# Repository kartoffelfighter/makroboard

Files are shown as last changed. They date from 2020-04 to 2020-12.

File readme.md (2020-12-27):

# Makroboard 

This keyboard has 8 cherry switches and 8 rgb-leds, connected to an ATMEGA32U4 (Arduino Leonardo) to emulate a keyboard.

Its porpuse is to store Makros which are not defined per default on a keyboard

## Keys

Default layout (in firmware folder)

| CTRL + F1  | CTRL + F2 | CTRL + F3  | CTRL + F4  |
| --- | --- | --- | --- |
| Media_PREV | Media_PAUSE | Media_NEXT | Media_STOP |
| | | | |
## Dependencies

The firmware uses the FastLed and Project-HID Librarys. You can find these on github, but also in the arduino library manager.

[FastLed (FastLED)]: https://github.com/FastLED/FastLED
[Project-HID (NicoHood)]: https://github.com/NicoHood/HID

### Notes

The Source code is not optimized and might hang sometimes. Since i'm using this board at most to control my teamspeak-mute i didn't care to optimize. If you wan't to, feel free.

Software and Hardware come as-is without any warranty.

My board was etched at jlcpcb, parts came from mouser, assembling was done by hand. 

If you're interested in a board feel free to contact me, i do still have some laying here.

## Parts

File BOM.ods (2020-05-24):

 | Artikel | Preis | Stk | Gesamt
 | Leiterplatte | 1,68 € | 1 | 1,68 €
 | Cherry Switch | 0,43 € | 8 | 3,41 €
 | ATMEGA | 3,60 € | 1 | 3,60 €
 | Quarz | 0,36 € | 1 | 0,36 €
 | Type-C Buchse | 1,58 € | 1 | 1,58 €
 | Neopixel LED | 0,10 € | 8 | 0,80 €
 |  |  |  | 11,42 €
PCB
 | 100nF |  | 10
 | 22pF |  | 2
 | 1µF |  | 1
 | WS2812B |  | 8
 | Type-C Buchse |  | 1
 | 10k |  | 9
 | 22R |  | 2
 | 0R0 |  | 1
 | Varistor |  | 2
 | Cherry Switch |  | 8
 | ATMEGA |  | 1
 | 16MHz |  | 1

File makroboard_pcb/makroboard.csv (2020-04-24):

Source: | C:\Users\marc\Google Drive\Projekte\makroboard\makroboard_pcb\makroboard.sch
Date: | 18.04.2020 20:56:32
Tool: | Eeschema (5.1.5)-3
Component Count: | 73
Ref | Value | Footprint | Datasheet | Manufacturer | Vendor
C1 | 100n | Capacitor_SMD:C_0603_1608Metric | ~
C2 | 100n | Capacitor_SMD:C_0603_1608Metric | ~
C3 | 100n | Capacitor_SMD:C_0603_1608Metric | ~
C4 | 100n | Capacitor_SMD:C_0603_1608Metric | ~
C5 | 100n | Capacitor_SMD:C_0603_1608Metric | ~
C6 | 100n | Capacitor_SMD:C_0603_1608Metric | ~
C7 | 100n | Capacitor_SMD:C_0603_1608Metric | ~
C8 | 100n | Capacitor_SMD:C_0603_1608Metric | ~
C9 | 100n | Capacitor_SMD:C_0603_1608Metric | ~
C10 | 100n | Capacitor_SMD:C_0603_1608Metric | ~
C11 | 22pF | Capacitor_SMD:C_0603_1608Metric | ~
C12 | 22pF | Capacitor_SMD:C_0603_1608Metric | ~
C13 | 100n | Capacitor_SMD:C_0603_1608Metric | ~
C14 | 1µ | Capacitor_SMD:C_0603_1608Metric | ~
C15 | C | Capacitor_SMD:C_0603_1608Metric | ~
C16 | C | Capacitor_SMD:C_0603_1608Metric | ~
C17 | CP | Capacitor_SMD:C_1206_3216Metric | ~
D1 | WS2812B | LED_SMD:LED_WS2812B_PLCC4_5.0x5.0mm_P3.2mm | https://cdn-shop.adafruit.com/datasheets/WS2812B.pdf
D2 | WS2812B | LED_SMD:LED_WS2812B_PLCC4_5.0x5.0mm_P3.2mm | https://cdn-shop.adafruit.com/datasheets/WS2812B.pdf
D3 | WS2812B | LED_SMD:LED_WS2812B_PLCC4_5.0x5.0mm_P3.2mm | https://cdn-shop.adafruit.com/datasheets/WS2812B.pdf
D4 | WS2812B | LED_SMD:LED_WS2812B_PLCC4_5.0x5.0mm_P3.2mm | https://cdn-shop.adafruit.com/datasheets/WS2812B.pdf
D5 | WS2812B | LED_SMD:LED_WS2812B_PLCC4_5.0x5.0mm_P3.2mm | https://cdn-shop.adafruit.com/datasheets/WS2812B.pdf
D6 | WS2812B | LED_SMD:LED_WS2812B_PLCC4_5.0x5.0mm_P3.2mm | https://cdn-shop.adafruit.com/datasheets/WS2812B.pdf
D7 | WS2812B | LED_SMD:LED_WS2812B_PLCC4_5.0x5.0mm_P3.2mm | https://cdn-shop.adafruit.com/datasheets/WS2812B.pdf
D8 | WS2812B | LED_SMD:LED_WS2812B_PLCC4_5.0x5.0mm_P3.2mm | https://cdn-shop.adafruit.com/datasheets/WS2812B.pdf
H1 | MountingHole_Pad | MountingHole:MountingHole_3.2mm_M3_Pad | ~
H2 | MountingHole_Pad | MountingHole:MountingHole_3.2mm_M3_Pad | ~
H3 | MountingHole_Pad | MountingHole:MountingHole_3.2mm_M3_Pad | ~
H4 | MountingHole_Pad | MountingHole:MountingHole_3.2mm_M3_Pad | ~
J1 | TX1+ | TestPoint:TestPoint_Pad_D1.0mm | ~
J2 | TX1- | TestPoint:TestPoint_Pad_D1.0mm | ~
J3 | TX2+ | TestPoint:TestPoint_Pad_D1.0mm | ~
J4 | TX2- | TestPoint:TestPoint_Pad_D1.0mm | ~
J5 | SBU1 | TestPoint:TestPoint_Pad_D1.0mm | ~
J6 | SBU2 | TestPoint:TestPoint_Pad_D1.0mm | ~
J7 | RX1+ | TestPoint:TestPoint_Pad_D1.0mm | ~
J8 | RX1- | TestPoint:TestPoint_Pad_D1.0mm | ~
J9 | RX2+ | TestPoint:TestPoint_Pad_D1.0mm | ~
J10 | RX2- | TestPoint:TestPoint_Pad_D1.0mm | ~
J11 | 105450-0101 | type-c:MOLEX_105450-0101 | Molex
J12 | ICSP | Connector_PinHeader_2.54mm:PinHeader_2x03_P2.54mm_Vertical | ~
J13 | +5V | Connector_PinHeader_2.54mm:PinHeader_1x10_P2.54mm_Vertical | ~
J14 | DIG_IO_2 | Connector_PinHeader_2.54mm:PinHeader_1x10_P2.54mm_Vertical | ~
J15 | DIG_IO_1 | Connector_PinHeader_2.54mm:PinHeader_1x10_P2.54mm_Vertical | ~
J16 | GND | Connector_PinHeader_2.54mm:PinHeader_1x10_P2.54mm_Vertical | ~
J17 | ANALOG_IO | Connector_PinHeader_2.54mm:PinHeader_1x06_P2.54mm_Vertical | ~
R1 | 10k | Resistor_SMD:R_0603_1608Metric | ~
R2 | 10k | Resistor_SMD:R_0603_1608Metric | ~
R3 | 10k | Resistor_SMD:R_0603_1608Metric | ~
R4 | 10k | Resistor_SMD:R_0603_1608Metric | ~
R5 | 10k | Resistor_SMD:R_0603_1608Metric | ~
R6 | 10k | Resistor_SMD:R_0603_1608Metric | ~
R7 | 10k | Resistor_SMD:R_0603_1608Metric | ~
R8 | 10k | Resistor_SMD:R_0603_1608Metric | ~
R9 | 10k | Resistor_SMD:R_0603_1608Metric | ~
R10 | 10k | Resistor_SMD:R_0603_1608Metric | ~
R11 | n.b. | Resistor_SMD:R_0603_1608Metric | ~
R12 | 56k | Resistor_SMD:R_0603_1608Metric | ~
R13 | 22R | Resistor_SMD:R_0603_1608Metric | ~
R14 | 22R | Resistor_SMD:R_0603_1608Metric | ~
R15 | 0R0 | Resistor_SMD:R_0603_1608Metric | ~
RV1 | Varistor | Resistor_SMD:R_0603_1608Metric | ~
RV2 | Varistor | Resistor_SMD:R_0603_1608Metric | ~
SW1 | SW_Push | Button_Switch_Keyboard:SW_Cherry_MX_1.50u_PCB | ~
SW2 | SW_Push | Button_Switch_Keyboard:SW_Cherry_MX_1.50u_PCB | ~
SW3 | SW_Push | Button_Switch_Keyboard:SW_Cherry_MX_1.50u_PCB | ~
SW4 | SW_Push | Button_Switch_Keyboard:SW_Cherry_MX_1.50u_PCB | ~
SW5 | SW_Push | Button_Switch_Keyboard:SW_Cherry_MX_1.50u_PCB | ~
SW6 | SW_Push | Button_Switch_Keyboard:SW_Cherry_MX_1.50u_PCB | ~
SW7 | SW_Push | Button_Switch_Keyboard:SW_Cherry_MX_1.50u_PCB | ~
SW8 | SW_Push | Button_Switch_Keyboard:SW_Cherry_MX_1.50u_PCB | ~
U1 | ATmega32U4-AU | Package_QFP:TQFP-44_10x10mm_P0.8mm | http://ww1.microchip.com/downloads/en/DeviceDoc/Atmel-7766-8-bit-AVR-ATmega16U4-32U4_Datasheet.pdf
Y1 | 16MHz | Crystal:Crystal_SMD_SeikoEpson_MA505-2Pin_12.7x5.1mm_HandSoldering | ~

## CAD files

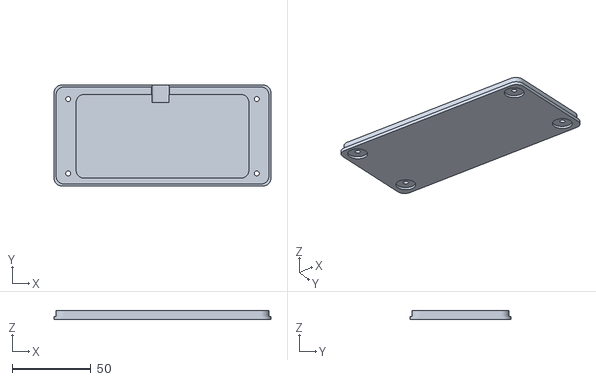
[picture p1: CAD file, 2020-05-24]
makroboard_case/case_bottom.stl
137.4 x 64.0 x 6.00

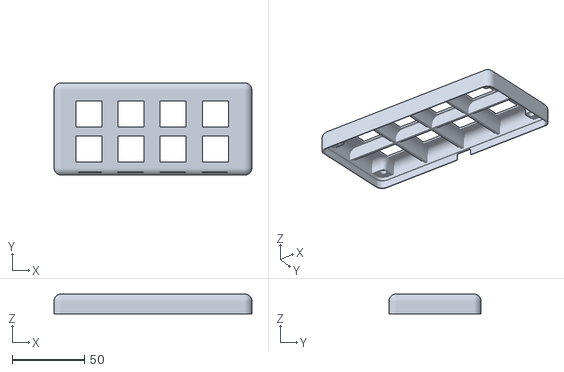
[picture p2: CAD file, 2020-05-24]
makroboard_case/case_top.stl
137.4 x 64.0 x 13.8

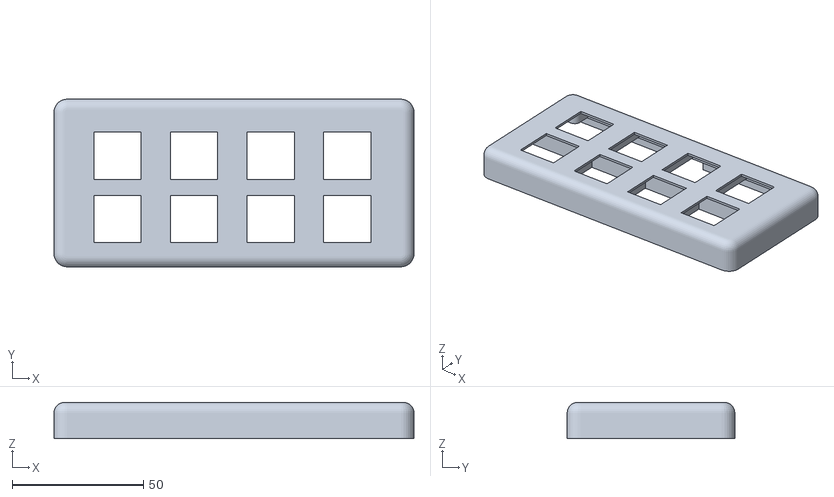
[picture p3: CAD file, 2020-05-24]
makroboard_case/case_top_v1.stl
137.4 x 64.0 x 13.8

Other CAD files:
makroboard_case/Baugruppe1.iam
makroboard_case/OldVersions/Baugruppe1.0002.iam
makroboard_case/OldVersions/case_bot.0001.ipt
makroboard_case/OldVersions/case_bottom.0001.ipt
makroboard_case/case_bot.ipt
makroboard_case/case_top.ipt
makroboard_pcb/1054500101.ipt
makroboard_pcb/MX_CLICK.ipt
makroboard_pcb/MX_DOWN.ipt
makroboard_pcb/MX_PIN.ipt
makroboard_pcb/MX_SPRING.ipt
makroboard_pcb/MX_UP.ipt
makroboard_pcb/UP_MX.ipt
makroboard_pcb/asm_mx_asm_PCB.iam

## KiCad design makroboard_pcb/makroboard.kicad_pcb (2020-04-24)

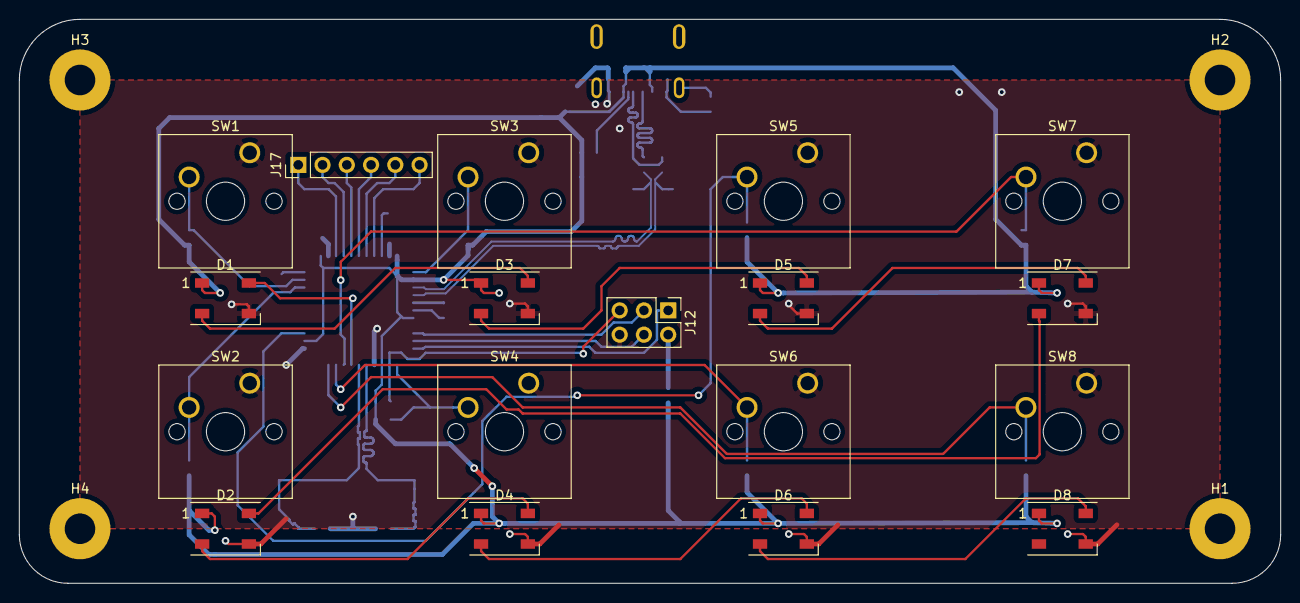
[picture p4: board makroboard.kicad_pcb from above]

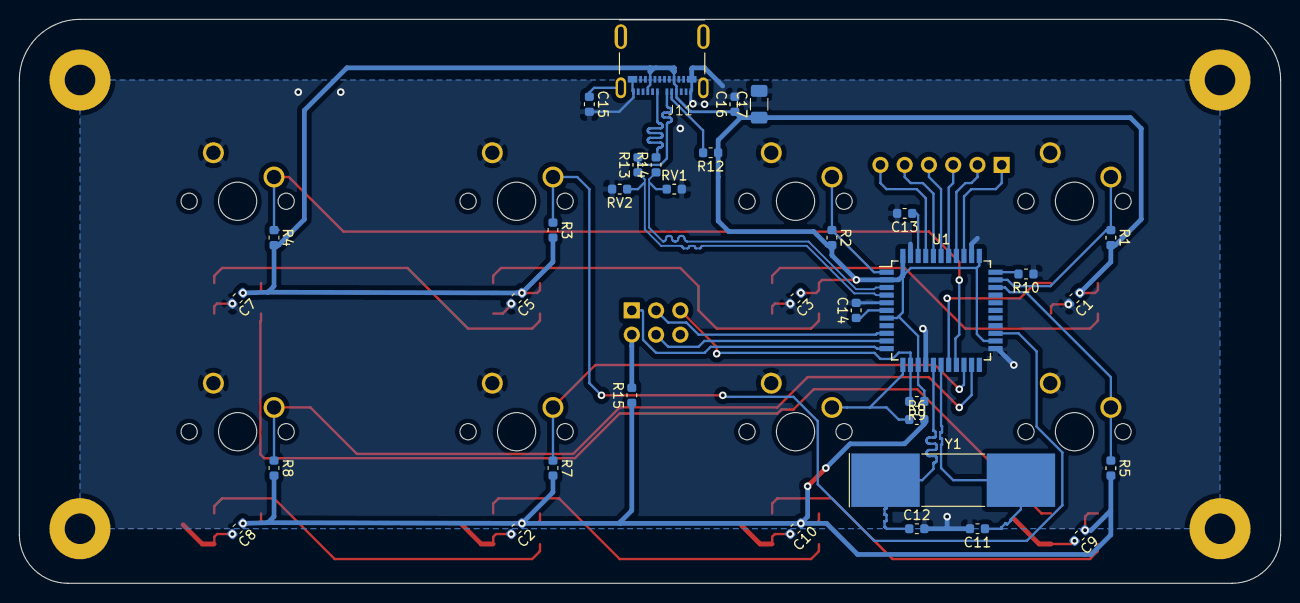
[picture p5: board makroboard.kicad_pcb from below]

Board: 2 copper layers, 132.1 x 59.1 mm, 56 parts (34 on the bottom side), 40 nets.

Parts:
C1, C2, C3, C5, C7, C8, C9, C10, C13: 100n; C_0603_1608Metric
C11, C12: 22pF; C_0603_1608Metric
C14: 1µ; C_0603_1608Metric
C15: 1nF; C_0603_1608Metric
C16: 100nF; C_0603_1608Metric
C17: 1µF; C_1206_3216Metric
D1, D2, D3, D4, D5, D6, D7, D8: WS2812B; LED_WS2812B_PLCC4_5.0x5.0mm_P3.2mm
H1, H2, H3, H4: MountingHole_Pad; MountingHole_3.2mm_M3_Pad
J11: 105450-0101; MOLEX_105450-0101
J12: ICSP; PinHeader_2x03_P2.54mm_Vertical
J17: ANALOG_IO; PinHeader_1x06_P2.54mm_Vertical
R1, R2, R3, R4, R5, R6, R7, R8, R9, R10: 10k; R_0603_1608Metric
R12: 56k; R_0603_1608Metric
R13, R14: 22R; R_0603_1608Metric
R15: 0R0; R_0603_1608Metric
RV1, RV2: Varistor; R_0603_1608Metric
SW1, SW2, SW3, SW4, SW5, SW6, SW7, SW8: SW_Push; SW_Cherry_MX_1.50u_PCB
U1: ATmega32U4-AU; TQFP-44_10x10mm_P0.8mm
Y1: 16MHz; Crystal_SMD_SeikoEpson_MA505-2Pin_12.7x5.1mm_HandSoldering

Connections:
+5V: C1.1, C2.1, C3.1, C5.1, C7.1, C8.1, C9.1, C10.1, C16.1, C17.1, D1.1, D2.1, D3.1, D4.1, D5.1, D6.1, D7.1, D8.1, J11.A4, J11.A9, J11.B4, J11.B9, R1.2, R2.2, R3.2, R4.2, R5.2, R6.2, R7.2, R8.2, R9.1, R12.1, R15.1, U1.2, U1.7, U1.14, U1.24, U1.34, U1.44
A0: J17.1, U1.36
A1: J17.2, U1.37
A2: J17.3, U1.38
A3: J17.4, U1.39
A4: J17.5, U1.40
A5: J17.6, U1.41
D0: R7.1, SW6.2, U1.20
D1: R8.1, SW8.2, U1.21
D2: R4.1, SW7.2, U1.19
D3: D1.4, U1.18
D4: R3.1, SW5.2, U1.25
D5: R5.1, SW2.2, U1.31
D7: R2.1, SW3.2, U1.1
D11: R6.1, SW4.2, U1.12
D13: R1.1, SW1.2, U1.32
GND: C1.2, C2.2, C3.2, C5.2, C7.2, C8.2, C9.2, C10.2, C11.2, C12.2, C13.2, C14.2, C15.2, C16.2, C17.2, D1.3, D2.3, D3.3, D4.3, D5.3, D6.3, D7.3, D8.3, J11.A1, J11.A12, J11.B1, J11.B12, J12.6, R10.1, RV1.2, RV2.2, SW1.1, SW2.1, SW3.1, SW4.1, SW5.1, SW6.1, SW7.1, SW8.1, U1.5, U1.15, U1.23, U1.35, U1.43
MISO: J12.1, U1.11
MOSI: J12.4, U1.10
unnamed: C11.1, U1.17, Y1.2
unnamed: C12.1, U1.16, Y1.1
unnamed: C13.1, U1.42
unnamed: C14.1, U1.6
unnamed: C15.1, J11.S1, J11.S2, J11.S3, J11.S4
unnamed: D1.2, D3.4
unnamed: D2.2, D4.4
unnamed: D2.4, D7.2
unnamed: D3.2, D5.4
unnamed: D4.2, D6.4
unnamed: D5.2, D7.4
unnamed: D6.2, D8.4
unnamed: J11.A5, R12.2
unnamed: J11.A6, R13.2
unnamed: J11.A7, R14.2
unnamed: J12.2, R15.2
unnamed: R10.2, U1.33
RESET: J12.5, R9.2, U1.13
SCK: J12.3, U1.9
USB_D+: R13.1, RV2.1, U1.4
USB_D-: R14.1, RV1.1, U1.3

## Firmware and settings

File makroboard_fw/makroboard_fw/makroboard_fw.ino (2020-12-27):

//// Makroboard
// KEYS:
#include <HID-Project.h>
#define LAYOUT_GERMAN
/**
   |---------|---------|---------|---------|
   |--Key 1--|--Key 2--|--Key 3--|--Key 4--|
   |--Vol X--|--Vol- --|--Vol+ --|--MUTE --|
   |---------|---------|---------|---------|
   |--PREV --|--PAUSE--|--NEXT --|--STOP --|
   |---------|---------|---------|---------|
*/

// see all keys @ https://github.com/NicoHood/HID/wiki/Consumer-API
// note: all keys for the default keyboard layout will be sent with a pressed left CTRL to ensure no complications with other software. if you don't need that, dig deeper in the code.


#define KEY_1 KEY_F1  // F1
#define KEY_1_CONSUMER false
#define KEY_2 KEY_F2  // F2
#define KEY_2_CONSUMER false
#define KEY_3 KEY_F3  // F3
#define KEY_3_CONSUMER false
#define KEY_4 KEY_F4  // F4
#define KEY_4_CONSUMER false
#define KEY_5 MEDIA_PREVIOUS    // Previos Track
#define KEY_5_CONSUMER true
#define KEY_6 MEDIA_PLAY_PAUSE  // PlayPause
#define KEY_6_CONSUMER true
#define KEY_7 MEDIA_NEXT    // Next Track
#define KEY_7_CONSUMER true
#define KEY_8 MEDIA_STOP  // Stop
#define KEY_8_CONSUMER true

/**
   ----------------------------------------------------------------------------------
   EDIT only VALUES ABOVE
   ----------------------------------------------------------------------------------
*/

// Constants:
#define DEBOUNCE_TIME 15 // debounce time in ms. modify to lower if you think its to slow, to higher if its to clicky
#define DEBOUNCE_TRESHOLD 4 // modify only if you have misreads
#define LOOP_TIME 100 // communication loop to pc - the register with keystrokes gets polled in the loop and send as keys to the pc
#define MIN_LOOP_TIME 10  //mS a loop should take in minimum, arduinos get somehow a hiccup when running to fast

byte DEFINED_KEY[8] = {KEY_1, KEY_2, KEY_3, KEY_4, KEY_5, KEY_6, KEY_7, KEY_8};
bool KEY_LIB[8] = {KEY_1_CONSUMER, KEY_2_CONSUMER, KEY_3_CONSUMER, KEY_4_CONSUMER, KEY_5_CONSUMER, KEY_6_CONSUMER, KEY_7_CONSUMER, KEY_8_CONSUMER};

#include "pinconfig.h"

// LEDs Library
#include <FastLED.h>
CRGB leds[NUM_LEDS];

int debounce[8] = {0, 0, 0, 0, 0, 0, 0, 0};
long last_debounce_millis = 0;
long last_loop_time = 0;
long begin_time_loop = 0; // store the loop begin time to prevent the arduino from 'running-to-fast-hiccup'

void setup() {

  pinMode(SW0, INPUT);
  pinMode(SW1, INPUT);
  pinMode(SW2, INPUT);
  pinMode(SW3, INPUT);
  pinMode(SW4, INPUT);
  pinMode(SW5, INPUT);
  pinMode(SW6, INPUT);
  pinMode(SW7, INPUT);


  FastLED.addLeds<NEOPIXEL, LEDs>(leds, NUM_LEDS);

  // circle all leds one time
  for (int i = 0; i < NUM_LEDS; i++) {
    leds[i] = CRGB::Red;
    FastLED.show();
    delay(200);
    leds[i] = CRGB::Black;
    FastLED.show();
  }

  //Keyboard.begin();
  Consumer.begin();
  Keyboard.begin();
}

int leds_enabled[8] = {0, 0, 0, 0, 0, 0, 0, 0};
#define ANIMATION_DELAY 50

void animationPlayPause() {
  leds[4] = CRGB::Blue;
  leds[5] = CRGB::Green;
  leds[6] = CRGB::Blue;
  leds[7] = CRGB::Blue;
  FastLED.show();
  delay(ANIMATION_DELAY);
  leds[4] = CRGB::Black;
  leds[5] = CRGB::Black;
  leds[6] = CRGB::Black;
  leds[7] = CRGB::Black;
  FastLED.show();
  delay(ANIMATION_DELAY);
  leds[4] = CRGB::Blue;
  leds[5] = CRGB::Green;
  leds[6] = CRGB::Blue;
  leds[7] = CRGB::Blue;
  FastLED.show();
  delay(ANIMATION_DELAY);
  leds[4] = CRGB::Black;
  leds[5] = CRGB::Green;
  leds[6] = CRGB::Black;
  leds[7] = CRGB::Red;
  FastLED.show();
}

void animationStop() {
  leds[4] = CRGB::Red;
  FastLED.show();
  delay(ANIMATION_DELAY);
  leds[4] = CRGB::Red;
  leds[5] = CRGB::Red;
  FastLED.show();
  delay(ANIMATION_DELAY);
  leds[4] = CRGB::Red;
  leds[5] = CRGB::Red;
  leds[6] = CRGB::Red;
  FastLED.show();
  delay(ANIMATION_DELAY);
  leds[4] = CRGB::Red;
  leds[5] = CRGB::Red;
  leds[6] = CRGB::Red;
  leds[7] = CRGB::Red;
  FastLED.show();
  delay(20);
  leds[4] = CRGB::Black;
  leds[5] = CRGB::Black;
  leds[6] = CRGB::Black;
  leds[7] = CRGB::Red;
  FastLED.show();
}

void animationNext() {
  leds[4] = CRGB::Purple;
  leds[5] = CRGB::Green;
  leds[6] = CRGB::Green;
  leds[7] = CRGB::Green;
  FastLED.show();
  delay(ANIMATION_DELAY);
  leds[4] = CRGB::Green;
  leds[5] = CRGB::Purple;
  leds[6] = CRGB::Green;
  leds[7] = CRGB::Green;
  FastLED.show();
  delay(ANIMATION_DELAY);
  leds[4] = CRGB::Green;
  leds[5] = CRGB::Green;
  leds[6] = CRGB::Purple;
  leds[7] = CRGB::Green;
  FastLED.show();
  delay(ANIMATION_DELAY);
  leds[4] = CRGB::Green;
  leds[5] = CRGB::Green;
  leds[6] = CRGB::Green;
  leds[7] = CRGB::Purple;
  FastLED.show();
  delay(ANIMATION_DELAY);
  leds[4] = CRGB::Black;
  leds[5] = CRGB::Green;
  leds[6] = CRGB::Black;
  leds[7] = CRGB::Red;
  FastLED.show();
}

void animationPrevious() {
  leds[4] = CRGB::Green;
  leds[5] = CRGB::Green;
  leds[6] = CRGB::Green;
  leds[7] = CRGB::Purple;
  FastLED.show();
  delay(ANIMATION_DELAY);
  leds[4] = CRGB::Green;
  leds[5] = CRGB::Green;
  leds[6] = CRGB::Purple;
  leds[7] = CRGB::Green;
  FastLED.show();
  delay(ANIMATION_DELAY);
  leds[4] = CRGB::Green;
  leds[5] = CRGB::Purple;
  leds[6] = CRGB::Green;
  leds[7] = CRGB::Green;
  FastLED.show();
  delay(ANIMATION_DELAY);
  leds[4] = CRGB::Purple;
  leds[5] = CRGB::Green;
  leds[6] = CRGB::Green;
  leds[7] = CRGB::Green;
  FastLED.show();
  delay(ANIMATION_DELAY);
  leds[4] = CRGB::Black;
  leds[5] = CRGB::Green;
  leds[6] = CRGB::Black;
  leds[7] = CRGB::Red;
  FastLED.show();
}

void ledShow(byte key) {
  switch (key) {
    case 4:
      animationPrevious();
      break;
    case 5:
      animationPlayPause();
      break;
    case 6:
      animationNext();
      break;
    case 7:
      animationStop();
      break;
  }
}

void toggleLed(int key, bool self, int state = -1) {
  if (KEY_LIB[key]) {
    ledShow(key);
  } else {
    if (leds_enabled[key]) {
      if (state != on) {
        leds[key] = CRGB::Black;
        leds_enabled[key] = 0;
      }
    } else {
      if (state != off) {
        leds[key] = self ? CRGB::Blue : CRGB::Red;
        leds_enabled[key] = 1;
      }
    }
  }
}


void KeyPress(int key) {
  toggleLed(key, true);
  FastLED.show();
  if (KEY_LIB[key]) {
    Consumer.write(DEFINED_KEY[key]);
  } else {
    Keyboard.press(KEY_LEFT_CTRL);
    Keyboard.write(DEFINED_KEY[key]);
    Keyboard.releaseAll();
  }

}


void loop() {
  begin_time_loop = millis();
  /**
     Debounce:
     read all pins over again in the loop. increment the representing value in debounce after DEBOUNCE_TIME. after reading in loop check the array for values above 5 (450ms high should be fine)
  */
  if (millis() - DEBOUNCE_TIME > last_debounce_millis) { // check, if the last debouncing time is longer ago than the treshold for the next click increment
    last_debounce_millis = millis();
    if (!digitalRead(SW0)) debounce[0]++;
    if (!digitalRead(SW1)) debounce[1]++;
    if (!digitalRead(SW2)) debounce[2]++;
    if (!digitalRead(SW3)) debounce[3]++;
    if (!digitalRead(SW4)) debounce[4]++;
    if (!digitalRead(SW5)) debounce[5]++;
    if (!digitalRead(SW6)) debounce[6]++;
    if (!digitalRead(SW7)) debounce[7]++;
  }

  if (millis() - LOOP_TIME > last_loop_time) {
    for (int i = 0; i < 8; i++) {
      if (debounce[i] > DEBOUNCE_TRESHOLD) {
        debounce[i] = 0;
        KeyPress(i);
      }
    }
  }
  if (millis() - begin_time_loop > MIN_LOOP_TIME)
    delay(MIN_LOOP_TIME);
}
